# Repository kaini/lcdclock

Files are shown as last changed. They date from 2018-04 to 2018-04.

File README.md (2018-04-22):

# 7-Segment LCD Clock

Schematic, PCB and firmware (C++) for a 7-segment LCD clock. For details please
see [my site](https://me.pushrax.com/lcd-clock/).

## Build Instructions

Just use `make`. If you want a release build use `make RELEASE=1`. If you
have a SEGGER J-Link you can use `make flash` to flash the build output
onto a compatible microcontroller.

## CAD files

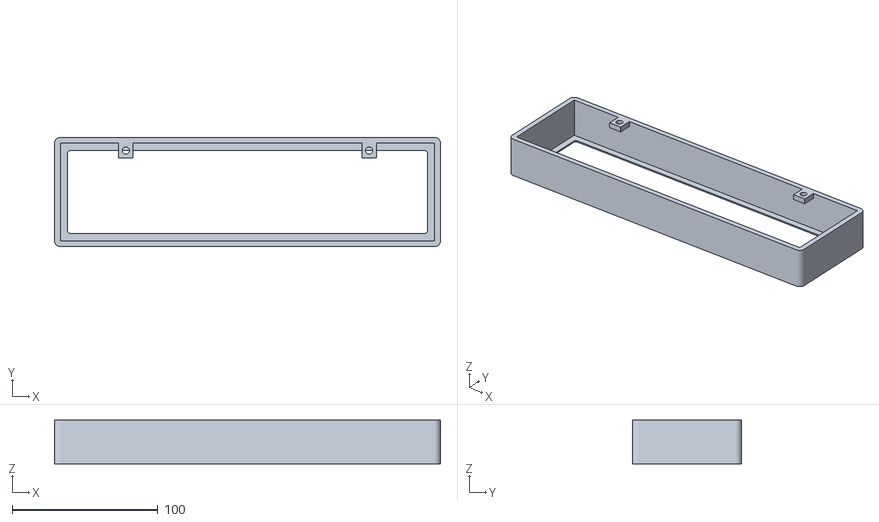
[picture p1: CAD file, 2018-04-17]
case.stl
265.0 x 75.0 x 30.0

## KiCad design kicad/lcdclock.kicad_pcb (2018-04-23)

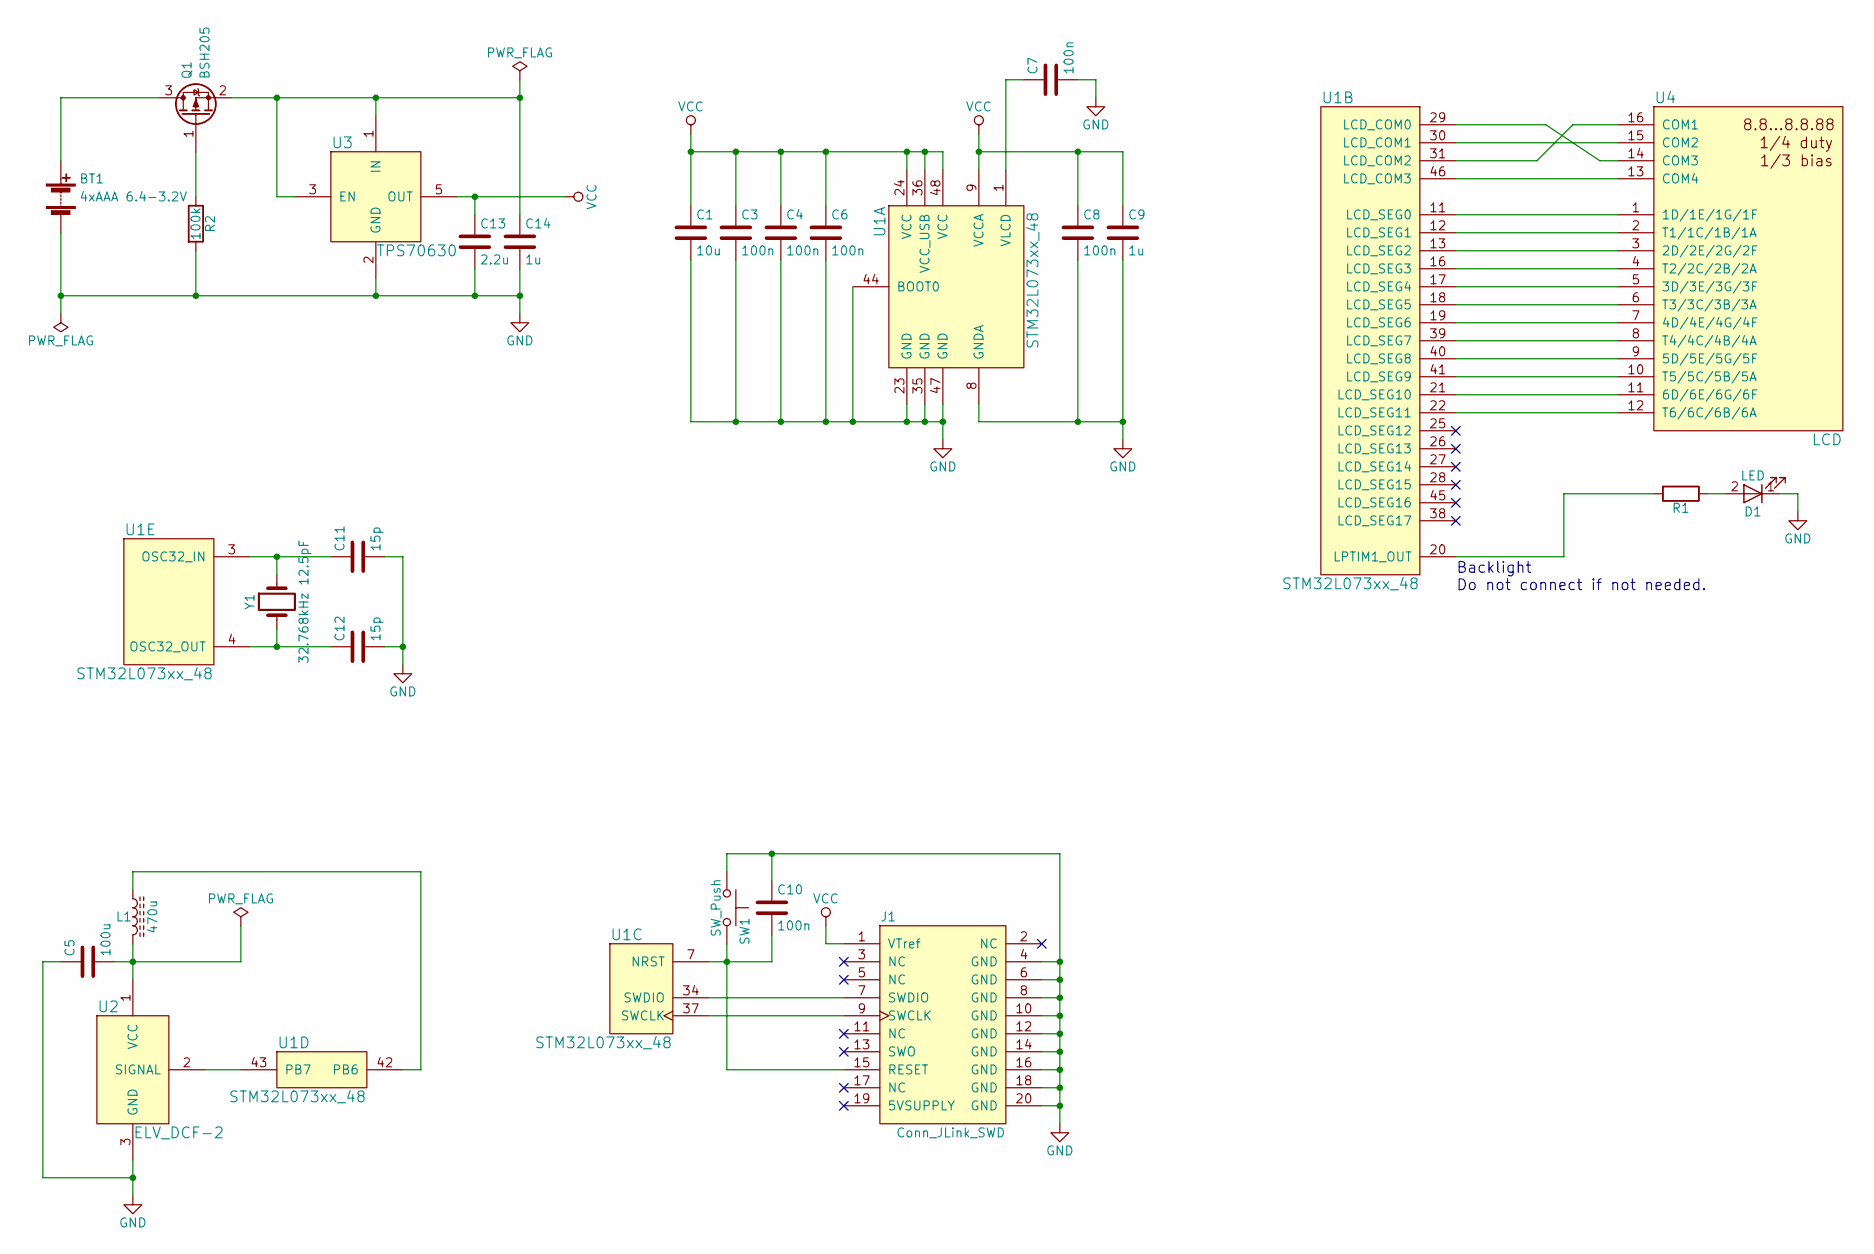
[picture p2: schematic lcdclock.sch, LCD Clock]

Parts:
BT1: 4xAAA 6.4-3.2V; CONNECTOR_2x1
C1: 10u; R_0805_HandSoldering
C3, C4, C6, C7, C8, C10: 100n; R_0805_HandSoldering
C5: 100u; R_1206_HandSoldering
C9, C14: 1u; R_0805_HandSoldering
C11, C12: 15p; R_0805_HandSoldering
C13: 2.2u; R_0805_HandSoldering
D1: LED; CONNECTOR_2x1
J1: Conn_JLink_SWD; IDC_Header_Straight_20pins
L1: 470u; R_1812_HandSoldering
Q1: BSH205; SOT-23_Handsoldering
R1: ?; R_0805_HandSoldering
R2: 100k; R_0805_HandSoldering
SW1: SW_Push; SW_SPST_B3S-1000
U1: STM32L073xx_48; LQFP-48_7x7mm_Pitch0.5mm
U2: ELV_DCF-2; CONNECTOR_3x1
U3: TPS70630; SOT-23-5_HandSoldering
U4: LCD; IDC_Header_Straight_16pins
Y1: 32.768kHz 12.5pF; Crystal_SMD_SeikoEpson_MC405-2pin_9.6x4.1mm

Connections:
GND: BT1.2 (-), C1.2, C3.2, C4.2, C5.1, C6.2, C7.2, C8.2, C9.2, C10.1, C11.2, C12.2, C13.2, C14.2, D1.1 (K), J1.4 (GND), J1.6 (GND), J1.8 (GND), J1.10 (GND), J1.12 (GND), J1.14 (GND), J1.16 (GND), J1.18 (GND), J1.20 (GND), R2.2, SW1.1, U1.8 (GNDA), U1.23 (GND), U1.35 (GND), U1.44 (BOOT0), U1.47 (GND), U2.3 (GND), U3.2 (GND)
unnamed: BT1.1 (+), Q1.3 (D)
unnamed: C5.2, L1.2, U2.1 (VCC)
unnamed: C7.1, U1.1 (VLCD)
unnamed: C10.2, J1.15 (RESET), SW1.2, U1.7 (NRST)
unnamed: C11.1, U1.3 (OSC32_IN), Y1.1
unnamed: C12.1, U1.4 (OSC32_OUT), Y1.2
unnamed: C14.1, Q1.2 (S), U3.1 (IN), U3.3 (EN)
unnamed: D1.2 (A), R1.1
unnamed: J1.7 (SWDIO), U1.34 (SWDIO)
unnamed: J1.9 (SWCLK), U1.37 (SWCLK)
unnamed: L1.1, U1.42 (PB6)
unnamed: Q1.1 (G), R2.1
unnamed: R1.2, U1.20 (LPTIM1_OUT)
unnamed: U1.11 (LCD_SEG0), U4.1 (1D/1E/1G/1F)
unnamed: U1.12 (LCD_SEG1), U4.2 (T1/1C/1B/1A)
unnamed: U1.13 (LCD_SEG2), U4.3 (2D/2E/2G/2F)
unnamed: U1.16 (LCD_SEG3), U4.4 (T2/2C/2B/2A)
unnamed: U1.17 (LCD_SEG4), U4.5 (3D/3E/3G/3F)
unnamed: U1.18 (LCD_SEG5), U4.6 (T3/3C/3B/3A)
unnamed: U1.19 (LCD_SEG6), U4.7 (4D/4E/4G/4F)
unnamed: U1.21 (LCD_SEG10), U4.11 (6D/6E/6G/6F)
unnamed: U1.22 (LCD_SEG11), U4.12 (T6/6C/6B/6A)
unnamed: U1.29 (LCD_COM0), U4.14 (COM3)
unnamed: U1.30 (LCD_COM1), U4.15 (COM2)
unnamed: U1.31 (LCD_COM2), U4.16 (COM1)
unnamed: U1.39 (LCD_SEG7), U4.8 (T4/4C/4B/4A)
unnamed: U1.40 (LCD_SEG8), U4.9 (5D/5E/5G/5F)
unnamed: U1.41 (LCD_SEG9), U4.10 (T5/5C/5B/5A)
unnamed: U1.43 (PB7), U2.2 (SIGNAL)
unnamed: U1.46 (LCD_COM3), U4.13 (COM4)
VCC: C1.1, C3.1, C4.1, C6.1, C8.1, C9.1, C13.1, J1.1 (VTref), U1.9 (VCCA), U1.24 (VCC), U1.36 (VCC_USB), U1.48 (VCC), U3.5 (OUT)

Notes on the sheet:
Backlight Do not connect if not needed.

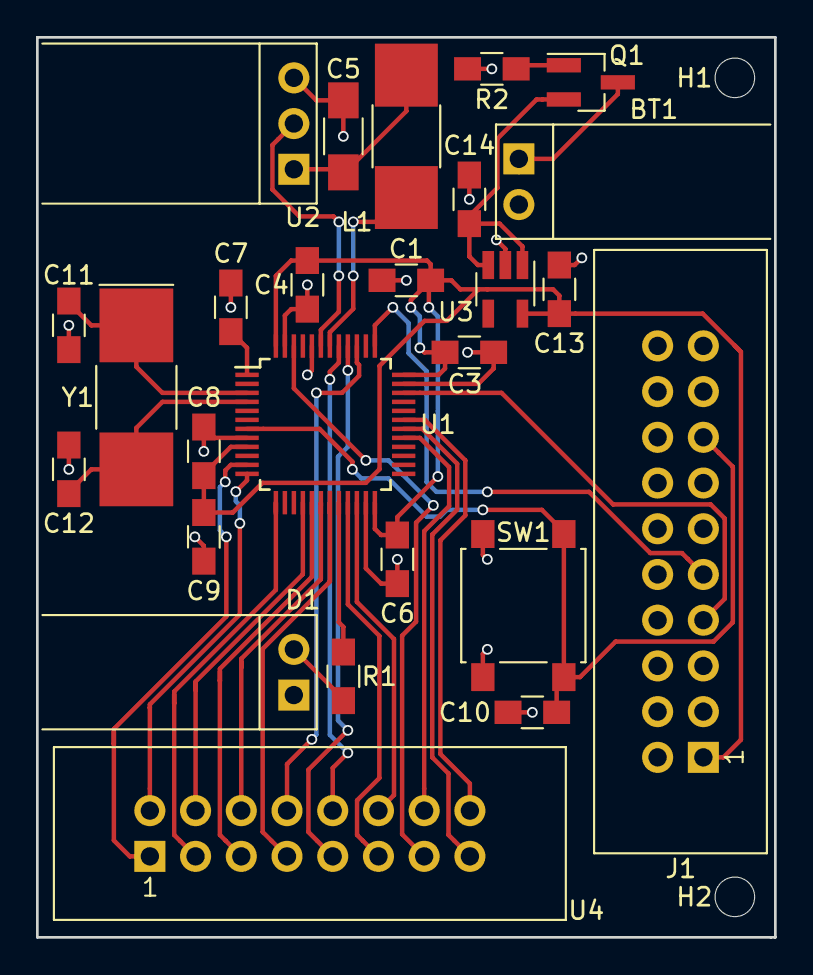
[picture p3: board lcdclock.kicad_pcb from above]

Board: 2 copper layers, 41.0 x 50.0 mm, 28 parts (0 on the bottom side), 32 nets.

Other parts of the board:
H1, H2: MountingHole_2.2mm_M2

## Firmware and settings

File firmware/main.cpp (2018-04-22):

#include "dcf77.hpp"
#include "dcf77_parser.hpp"
#include "display.hpp"
#include "rtc.hpp"
#include "utils.hpp"
#include "critical_section.hpp"
#include <stm32l0xx.h>

// https://andriidevel.blogspot.co.at/2016/05/size-cost-of-c-exception-handling-on.html
// This removes the default terminate handler which unfortunately pulls a lot of pretty printing
// functions that amount to about 60 kB of code. Also we cannot output stuff, therefore who
// cares.
namespace __cxxabiv1 {
    std::terminate_handler __terminate_handler = abort;
}

namespace {

struct power_and_clocks {
    power_and_clocks() {
        // Enable the power interface clock
        SET_BIT(RCC->APB1ENR, RCC_APB1ENR_PWREN);

        // Go into the lowest power range (Range 3)
        while (READ_BIT(PWR->CSR, PWR_CSR_VOSF))
            ;
        MODIFY_REG(PWR->CR, PWR_CR_VOS_Msk, 0b11 << PWR_CR_VOS_Pos);
        while (READ_BIT(PWR->CSR, PWR_CSR_VOSF))
            ;

        // Set the MSE (multiple speed internal) oscillator to 1 MHz
        MODIFY_REG(RCC->ICSCR, RCC_ICSCR_MSIRANGE_Msk, RCC_ICSCR_MSIRANGE_4);
        while (!READ_BIT(RCC->CR, RCC_CR_MSIRDY))
            ;

        // Disable the RTC domain write protection
        SET_BIT(PWR->CR, PWR_CR_DBP);

        // Enable the 2^15 Hz LSE (low speed external) crystal and drive it in high drive mode
        MODIFY_REG(RCC->CSR, RCC_CSR_LSEDRV_Msk, (0b11 << RCC_CSR_LSEDRV_Pos) | RCC_CSR_LSEON);
        while (!READ_BIT(RCC->CSR, RCC_CSR_LSERDY))
            ;

        // Set the RTC/LCD clock to the LSE and enable the RTC
        MODIFY_REG(RCC->CSR, RCC_CSR_RTCSEL_Msk, (0b01 << RCC_CSR_RTCSEL_Pos) | RCC_CSR_RTCEN);

        // Enable LCD clock
        SET_BIT(RCC->APB1ENR, RCC_APB1ENR_LCDEN);
        SET_BIT(RCC->APB1SMENR, RCC_APB1SMENR_LCDSMEN);

        // Enable GPIO clocks
        SET_BIT(RCC->IOPENR, RCC_IOPENR_GPIOAEN | RCC_IOPENR_GPIOBEN);
        SET_BIT(RCC->IOPSMENR, RCC_IOPSMENR_GPIOASMEN | RCC_IOPSMENR_GPIOBSMEN);

        // Enable TIM2 clock
        SET_BIT(RCC->APB1ENR, RCC_APB1ENR_TIM2EN);
        SET_BIT(RCC->APB1SMENR, RCC_APB1SMENR_TIM2SMEN);
    }
};

}

static power_and_clocks power_and_clocks;
static hw::rtc rtc(RTC);
static hw::display display(LCD, {{GPIOA, {1, 2, 3, 6, 7, 8, 9, 10}}, {GPIOB, {0, 1, 3, 4, 5, 9, 10, 11}}});
static hw::dcf77 dcf(GPIOB, 6, GPIOB, 7, TIM2);

int main() {
    // Read and clear reset bit
    //const bool cold_boot = !READ_BIT(PWR->CSR, PWR_CSR_WUF);
    SET_BIT(PWR->CR, PWR_CR_CWUF);

    NVIC_EnableIRQ(RTC_IRQn);
    NVIC_SetPriority(RTC_IRQn, 200);
    SET_BIT(EXTI->IMR, EXTI_IMR_IM17);
    SET_BIT(EXTI->EMR, EXTI_EMR_EM17);
    SET_BIT(EXTI->RTSR, EXTI_RTSR_RT17);

    NVIC_EnableIRQ(TIM2_IRQn);
    NVIC_SetPriority(TIM2_IRQn, 20);

    bool need_sync = true;
    bool syncing = false;
    bool first_iteration = true;
    dcf77::parser parser;

    display.enable(true);

    while (true) {
        auto now = rtc.get_time();

        // Resynchronize each Sunday at 4:04 UTC.
        if (!need_sync && now.hour() == 4 && now.minute() == 4 && weekday(now) == 0) {
            // In theory this could trigger multiple syncs back-to-back if a single
            // sync finishes quicker than in one minute, but this impossible as long
            // as the clock did not drift too much.
            need_sync = true;
        }

    	if (need_sync && !syncing) {
			syncing = true;
			parser = dcf77::parser();
			dcf.enable();
			display.set_dot(1, true);
    	}

    	if (syncing && dcf.samples_pending()) {
    		auto samples = dcf.clear_pending_samples();
			if (parser.feed(&samples[0])) {
			    if (auto frame = parser.get_result()) {
                    rtc.set_time(*frame);
                    need_sync = false;
                    syncing = false;
                    dcf.disable();
                    display.set_dot(1, false);
			    }
			}
    	}

    	if (first_iteration || rtc.second_pending()) {
    		rtc.clear_second_pending();

    		auto localtime = now;
    		if (datetime::is_eu_dst(localtime)) {
    		    localtime.add_hours(2);
    		} else {
    		    localtime.add_hours(1);
    		}

			if (localtime.hour() < 10) {
				display.set_digit(0, hw::display_digit::none);
			} else {
			    display.set_digit(0, static_cast<hw::display_digit>(localtime.hour() / 10));
			}
			display.set_digit(1, static_cast<hw::display_digit>(localtime.hour() % 10));
			display.set_digit(2, static_cast<hw::display_digit>(localtime.minute() / 10));
			display.set_digit(3, static_cast<hw::display_digit>(localtime.minute() % 10));
			display.set_digit(4, static_cast<hw::display_digit>(localtime.second() / 10));
			display.set_digit(5, static_cast<hw::display_digit>(localtime.second() % 10));
			display.set_colon(true);
    	}

    	display.refresh();
    	first_iteration = false;

        // Done... for now
    	if (syncing) {
            // Simple sleep mode
            CLEAR_BIT(SCB->SCR, SCB_SCR_SLEEPDEEP_Msk);
        } else {
            // Stop mode
            SET_BIT(SCB->SCR, SCB_SCR_SLEEPDEEP_Msk);
        }
    	__disable_irq();
        bool something_pending = (syncing && dcf.samples_pending()) || rtc.second_pending();
        if (!something_pending) {
            __WFI();
        }
        __enable_irq();
    }

    return 0;
}

extern "C" void RTC_IRQHandler() {
    if (READ_BIT(RTC->ISR, RTC_ISR_ALRAF)) {
        {
            // Unfortunately the ISR register contains one read-write bit, that could be
            // changed. Therefore all non-atomic writes to this register have to be in a
            // critical section.
            hw::critical_section cs;
            CLEAR_BIT(RTC->ISR, RTC_ISR_ALRAF);
        }
        if (READ_BIT(EXTI->PR, EXTI_PR_PIF17)) {
            WRITE_REG(EXTI->PR, EXTI_PR_PIF17);
            rtc.irq_alarm_a();
        }
    }
}

extern "C" void TIM2_IRQHandler() {
    if (READ_BIT(TIM2->SR, TIM_SR_UIF)) {
        WRITE_REG(TIM2->SR, ~TIM_SR_UIF);
        dcf.irq_timer();
    }
}

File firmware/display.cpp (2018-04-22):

#include "display.hpp"
#include "utils.hpp"
#include <initializer_list>
#include <algorithm>
#include <stm32l0xx.h>

hw::display::display(LCD_TypeDef* lcd, pins pins) : m_lcd(lcd) {
    std::fill(m_digits.begin(), m_digits.end(), display_digit::none);
    std::fill(m_dots.begin(), m_dots.end(), false);

    for (const auto& pin_group : pins) {
        GPIO_TypeDef* gpio = std::get<0>(pin_group);
        for (const auto pin : std::get<1>(pin_group)) {
            // alternative function 1 (LCD)
            MODIFY_REG(gpio->AFR[GPIO_AFR_Idx(pin)], GPIO_AFR_AFSEL_Msk(pin), (0b0001 << GPIO_AFR_AFSEL_Pos(pin)));
            // no pullup/pulldown
            MODIFY_REG(gpio->PUPDR, GPIO_PUPDR_PUPD_Msk(pin), (0b00 << GPIO_PUPDR_PUPD_Pos(pin)));
            // high output speed
            MODIFY_REG(gpio->OSPEEDR, GPIO_OSPEEDER_OSPEED_Msk(pin), (0b10 << GPIO_OSPEEDER_OSPEED_Pos(pin)));
            // push/pull
            CLEAR_BIT(gpio->OTYPER, GPIO_OTYPER_OT(pin));
            // alternative function mode
            MODIFY_REG(gpio->MODER, GPIO_MODER_MODE_Msk(pin), (0b10 << GPIO_MODER_MODE_Pos(pin)));
        }
    }

    // 1/4 bias, 1/4 duty, external voltage
    MODIFY_REG(m_lcd->CR, LCD_CR_BIAS_Msk | LCD_CR_DUTY_Msk | LCD_CR_VSEL, (0b00 << LCD_CR_BIAS_Pos) | (0b011 << LCD_CR_DUTY_Pos));

    // 32768 rtc / 2^3 prescaler / 20 divider = 200 Hz; 200 Hz / 4 duty -> 50 Hz
    MODIFY_REG(
            m_lcd->FCR,
            LCD_FCR_PS_Msk | LCD_FCR_DIV_Msk | LCD_FCR_PON_Msk | LCD_FCR_DEAD_Msk,
            (3 << LCD_FCR_PS_Pos) | (4 << LCD_FCR_DIV_Pos) | (1 << LCD_FCR_PON_Pos) | (0 << LCD_FCR_DEAD_Pos) | (5 << LCD_FCR_CC_Pos) | LCD_FCR_HD);

    enable(false);
    refresh(true);
}

void hw::display::enable(bool enable) {
    if (enable) {
        SET_BIT(m_lcd->CR, LCD_CR_LCDEN);
    } else {
        CLEAR_BIT(m_lcd->CR, LCD_CR_LCDEN);
    }
    m_enabled = enable;
}

void hw::display::refresh(bool force) {
    if (!m_enabled || (!force && !m_need_refresh)) {
        return;
    }
    m_need_refresh = false;

	while (READ_BIT(m_lcd->SR, LCD_SR_UDR))
		;

	for (size_t i = 0; i < sizeof(m_lcd->RAM) / sizeof(m_lcd->RAM[0]); ++i) {
		WRITE_REG(m_lcd->RAM[i], 0);
	}

	for (size_t i = 0; i < m_digits.size(); ++i) {
	    render_digit(m_digits[i], i);
	}

	for (size_t i = 0; i < m_dots.size(); ++i) {
		if (m_dots[i]) {
			SET_BIT(m_lcd->RAM[4], 1 << (1 + 2 * i));
		}
	}

	if (m_colon) {
		SET_BIT(m_lcd->RAM[4], (1 << 9) | (1 << 11));
	}

	SET_BIT(m_lcd->SR, LCD_SR_UDR);
}

void hw::display::render_digit(display_digit digit, size_t pos) {
    static constexpr size_t segment_pin_offsets[] = { 1, 1, 1, 0, 0, 0, 0 };
    static constexpr size_t segment_coms[] = { 3, 0, 1, 2, 1, 3, 0 };
    static constexpr uint8_t digit_segments[] = {
    //    GFEDCBA <- segments active
        0b0111111,  // 0
        0b0000110,  // 1
        0b1011011,  // 2
        0b1001111,  // 3
        0b1100110,  // 4
        0b1101101,  // 5
        0b1111101,  // 6
        0b0000111,  // 7
        0b1111111,  // 8
        0b1101111,  // 9
        0b1000000,  // -
        0b0000000,  // (empty)
    };

    for (size_t segment = 0; segment < 7; ++segment) {
        if (digit_segments[static_cast<size_t>(digit)] & (1 << segment)) {
            size_t pin = 2 * pos + segment_pin_offsets[segment];
            SET_BIT(m_lcd->RAM[2 * segment_coms[segment]], 1 << pin);
        }
    }
}

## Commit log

2017-09-15 Add schematic
    [lcdclock.kicad_pcb, lcdclock.sch]
2017-09-16 Route PCB
    [lcdclock.kicad_pcb, lcdclock.sch]
2017-09-18 Rework for a STM32 CPU
    [lcdclock.sch]
2017-09-19 Change LCD and CPU to 48 pins
    [lcdclock.sch]
2017-09-20 Select parts and assign footprints
    [lcdclock.sch]
2017-09-20 Place components on PCB
    [lcdclock.kicad_pcb]
2017-09-20 Layout PCB
    [lcdclock.kicad_pcb, lcdclock.sch]
2017-09-20 Add two mounting holes
    [lcdclock.kicad_pcb]
2017-09-21 Add reverse voltage protection
    [lcdclock.kicad_pcb, lcdclock.sch]
2017-09-25 Replace crystal Y1 footprint with a smaller one
    [lcdclock.kicad_pcb, lcdclock.sch]
2017-09-29 Remove excessive track
    [lcdclock.kicad_pcb]
2017-09-29 Unify drill sizes
    [lcdclock.kicad_pcb]
2017-10-07 Assert refactoring and fix compiler warnings
    [display.c, main.c]
2017-10-23 Replace semihosting with SEGGER RTT and add working main loop
    [dcf77.c, display.c, main.c]
2017-10-31 Fix code bloat, fix missing static constructors, fix interrupt race condition
    [main.cpp]
2018-04-17 Fixes & add case
    [case.stl]
2018-04-21 Final fixes
    [lcdclock.kicad_pcb, lcdclock.sch]
2018-04-23 Fix two small issues in the PCB
    [lcdclock.kicad_pcb]
